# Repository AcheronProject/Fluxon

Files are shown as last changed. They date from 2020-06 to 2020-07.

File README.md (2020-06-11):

# Acheron 40-SM-S-STM32-MX-TH-WI (Codename "Fluxon")

Acheron Logo

See [this page](https://gondolindrim.github.io/AcheronDocs/fluxon/intro.html) for the Fluxon PCB documentation (still not written yet as of june of 2020).

## Introduction

The Fluxon is a replacement PCB for the Vortex Core keyboard. It supports the default layouts of the Vortex Core, with a 1.75-2.75 split spacebar. The PCB also supports two extra bottom row layouts: one with a 6.25 spacebar one and other with a 7 unit spacebar. See the picture below for details. 

The PCB is powered by a STM32L072CxTx and is QMK compatible.

The indicator LEDs of the stock PCB were substituted by SK6812 (WS2812-compatible controller-integrated seriallized RGB LEDs) which can be configured as per the QMK capabilities.

## Supported layouts

Click [this link](http://www.keyboard-layout-editor.com/#/gists/73be427d3e8086a9253feece2dae6974) for the KLE file for the Fluxon.

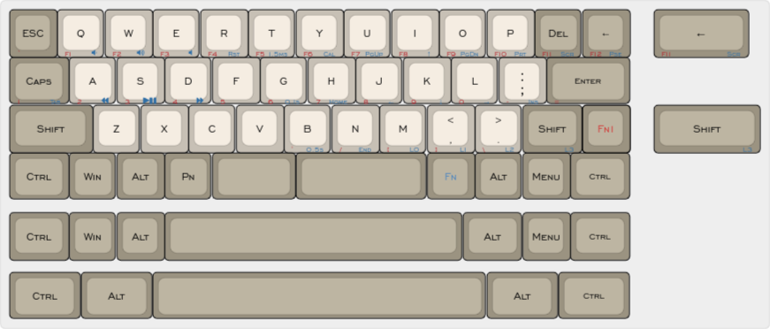
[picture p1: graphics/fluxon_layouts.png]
Fluxon layouts


## Renders

Fluxon bottom render
Fluxon top render

## Logo

The FLUXON logo was designed using the Deceptibots font by [Iconian Fonts](http://www.iconian.com/index.html). It was licensed for commercial use for this particular project through a donation. The FLUXON logo is therefore intellectual and commercial property of Álvaro "Gondolindrim" Volpato; the Deceptibots font is property of Iconian Fonts and their owners.

## Copyright notice

This project is released under the Acheron Open-Hardware License V1.2. For the license, please refer to the LICENCE.md file.

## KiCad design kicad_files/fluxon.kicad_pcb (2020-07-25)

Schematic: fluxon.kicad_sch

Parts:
C1, C2, C3: 100n; C_0805_2012Metric_Pad1.15x1.40mm_HandSolder
C4: 4.7nF; C_0805_2012Metric
C5, C6: 1u; CP_EIA-3216-10_Kemet-I_Pad1.58x1.35mm_HandSolder
C7: 4.7n; C_0805_2012Metric_Pad1.15x1.40mm_HandSolder
C8: 10u; C_0805_2012Metric_Pad1.15x1.40mm_HandSolder
C9, C10, C11, C15: 100n; C_0402_1005Metric
C12, C16: 4.7u; C_0402_1005Metric
C13: 1u; C_0402_1005Metric
C14: 10n; C_0402_1005Metric
C17: 1u; C_0805_2012Metric_Pad1.15x1.40mm_HandSolder
D1, D2, D3, D4, D5, D6, D7, D8, D9, D10, D11, D12, D13, D14, D15, D16, D17, D18, D19, D20, D21, D22, D23, D24, D25, D26, D27, D28, D29, D30, D31, D32, D33, D34, D35, D36, D37, D38, D39, D40, D41, D42, D43, D44, D45, D46, D47, D53: 1N4148W; D_SOD-123
D48, D49, D50: SK6812MINI-E; SK6812MINI_3535_6028_3.2x2.8mm_Round; MPN SK812MINI-E
D51: RB060M-60TR; D_SOD-123; Manufacturer Part Number RB060M-60TR; LCSC Part Number C114257
D52: SMF6.0A; D_SOD-123; Manufacturer Part Number SMF6.0A; LCSC Part Number C123790
F1: SL1210150; Fuse_1210_3225Metric; Manufacturer Part Number SL1210150; LCSC Part Number C70175
GR1: OSHLogo; osh-logo
GR2: Fluxon Plated Logo; fluxon_logo
GR3: Acheron Logo; acheronLong
GR4: Fluxon Big Logo; fluxon_logo_220x56.8mm
GR5, GR6, GR7: Warning Sign; warning_sign_3.6x3.2mm
J1: ARM SWD; Conn_ARM_JTAG_SWD_6
J2: U-F-M5DD-W-2; Korean-Hroparts_ U-F-M5DD-W-2; Manufacturer Part Number U-F-M5DD-W-2; LCSC Part Number C145793
J3: Conn_02x10; PinHeader_2x8_P2.54mm_Vertical
Q1: BSS138; SOT-23; Manufacturer Part Number BSS138; LCSC Part Number C193019
Q2: MUN5335DW1T1G; SOT-363_SC-70-6; Manufacturer Part Number MUN5335DW1T1G; LCSC Part Number C99680
R1, R2, R3: 3R; R_SMD_1206
R4, R6: 1k; R_SMD_1206
R5: 510R; R_SMD_1206
R7: 1M; R_SMD_1206
R8, R9, R13: 100k; R_SMD_1206
R10: 100R; R_SMD_1206
R11: 100; R_SMD_1206
R12: 33k; R_SMD_1206
S1: SW_Push; K2-1187SQ-A4SW-06; Manufacturer Part Number K2-1187SQ-A4SW-06; LCSC Part Number C92584
SW1: ESC; MX100
SW2: Q; MX100
SW3: W; MX100
SW4: E; MX100
SW5: R; MX100
SW6: T; MX100
SW7: Y; MX100
SW8: U; MX100
SW9: I; MX100
SW10: O; MX100
SW11: P; MX100
SW12: DEL; MX100
SW13: TAB_125; MX125
SW14: A; MX100
SW15: S; MX100
SW16: D; MX100
SW17: F; MX100
SW18: G; MX100
SW19: H; MX100
SW20: J; MX100
SW21: K; MX100
SW22: L; MX100
SW23: QUOTE; MX100
SW24: ENTER_175; MX175
SW25: LSHIFT_175; MX175
SW26: Z; MX100
SW27: X; MX100
SW28: C; MX100
SW29: V; MX100
SW30: B; MX100
SW31: N; MX100
SW32: M; MX100
SW33: COMMA; MX100
SW34: DOT; MX100
SW35: (D) RSHIFT_125; MX125
SW36: (D) FN_100; MX100
SW37: (F) RSHIFT_225; MX225
SW38: (I) RSHIFT_125; MX125
SW39: (I) SLASH_100; MX100
SW40: LCTRL_125; MX125
SW41: SUPER_100; MX100
SW42: LALT_100; MX100
SW43: SPC_625; MX625R
SW44: RALT_125; MX125
SW45: RGUI_100; MX100
SW46: RCTRL_125; MX125
SW47: BKSP; MX100
SW48: BKSP_2U; MX200
SW49: PN_100; MX100
SW50: SPC_175; MX175
SW51: SPC_275; MX275R
SW52: FN_100; MX100
SW53: RALT_100; MX100
SW54: LCTRL_150; MX150
SW55: LALT_150; MX150
SW56: SPC_700; MX700R
SW57: RCTRL_150; MX150
SW58: RALT_150; MX150
U1: USBLC6-2SC6; SOT-23-6; Manufacturer Part Number USBLC6-2SC6; LCSC Part Number C7519
U2: MCP1700-3302E/TT; SOT-23; Manufacturer Part Number MCP1700-3302E/TT; LCSC Part Number C39051
U3: STM32L072CBT6; LQFP-48_7x7mm_P0.5mm; Manufacturer Part Number STM32F072CBT6; LCSC Part Number C465977

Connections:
3.3V: C6.1, C9.2, C10.1, C11.2, C12.2, C13.2, C14.2, C15.2, C16.2, D51.2 (A), J1.1, J3.15, Q2.4 (C), R9.2, S1.1, U2.2 (VO), U3.1 (VBAT), U3.9 (VDDA), U3.24 (VDD), U3.36 (VDDIO2), U3.48 (VDD)
5V: C5.1, D51.1 (K), D52.1 (K), F1.1, R1.2, R2.1, R3.2, R4.2, R5.2, R8.2, U2.3 (VI)
/SHIELD: C4.2, J2.6 (Shield), R7.1
BOOT0: C8.2, R11.2, R12.1, R13.2, U3.44 (BOOT0)
Col1: SW1.1 (Col), SW13.1 (Col), SW25.1 (Col), SW40.1 (Col), SW54.1 (Col), U3.25 (PB12)
Col2: SW2.2 (Row), SW14.2 (Row), SW26.1 (Col), SW41.1 (Col), U3.11 (PA1/ADC_IN1)
Col3: SW3.1 (Col), SW15.1 (Col), SW27.1 (Col), SW42.1 (Col), SW55.1 (Col), U3.10 (PA0/ADC_IN0)
Col4: SW4.1 (Col), SW16.1 (Col), SW28.1 (Col), SW49.1 (Col), U3.6 (PF1/OSC_OUT)
Col5: SW5.1 (Col), SW17.1 (Col), SW29.1 (Col), SW50.1 (Col), U3.5 (PF0/OSC_IN)
Col6: SW6.1 (Col), SW18.1 (Col), SW30.1 (Col), SW43.1 (Col), SW51.1 (Col), SW56.1 (Col), U3.4 (PC15/OSC32_OUT)
Col7: SW7.1 (Col), SW19.1 (Col), SW31.1 (Col), U3.3 (PC14/OSC32_IN)
Col8: SW8.1 (Col), SW20.1 (Col), SW32.1 (Col), SW52.1 (Col), U3.2 (PC13)
Col9: SW9.1 (Col), SW21.1 (Col), SW33.1 (Col), SW44.1 (Col), SW53.1 (Col), SW57.1 (Col), U3.46 (SPI2_NSS/I2S2_WS/I2C1_SDA/TIM17_CH1/PB9)
Col10: SW10.1 (Col), SW22.1 (Col), SW34.1 (Col), SW45.1 (Col), U3.45 (I2C1_SCL/TIM16_CH1/PB8)
Col11: SW11.1 (Col), SW23.1 (Col), SW35.1 (Col), SW37.1 (Col), SW39.1 (Col), SW46.1 (Col), SW58.1 (Col), U3.43 (2C1_SDA/PB7)
Col12: SW12.1 (Col), SW24.1 (Col), SW36.1 (Col), SW38.1 (Col), SW47.2 (Row), SW48.2 (Row), U3.41 (SPI1_MOSI/I2S1_SD/TIM3_CH2/PB5)
D+: U1.6 (I/O1), U3.33 (USB_DP/PA12)
D-: U1.4 (I/O2), U3.32 (USB_DM/TIM1_CH4/PA11)
DBus+: J2.3 (D+), U1.1 (I/O1)
DBus-: J2.2 (D-), U1.3 (I/O2)
EXTRA3: J3.1, U3.30 (TIM1_CH2/PA9)
EXTRA5: J3.3, U3.29 (TIM1_CH1/PA8)
EXTRA6: J3.2, U3.31 (TIM1_CH3/PA10)
EXTRA8: J3.4, U3.27 (SPI2_MISO/I2S2_MCK/I2C2_SDA/TIM15_CH1/P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)
EXTRA9: J3.5, U3.22 (PB11/TIM2_CH4/I2C2_SDA)
EXTRA10: J3.6, U3.21 (PB10/SPI2_SCK/I2C2_SCL/TIM2_CH3)
EXTRA11: J3.7, U3.20 (PB2)
EXTRA12: J3.8, U3.19 (PB1/TIM3_CH4/TIM14_CH1/ADC_IN9)
EXTRA13: J3.9, U3.18 (PB0/TIM3_CH3/ADC_IN8)
EXTRA14: J3.10, U3.17 (PA7/TIM3_CH2/TIM14_CH1/ADC_IN7)
EXTRA15: J3.11, U3.16 (PA6/ADC_IN6/TIM3_CH1/TIM16_CH1)
EXTRA16: J3.12, U3.15 (PA5/ADC_IN5/DAC_OUT2)
EXTRA17: J3.13, U3.14 (PA4/TIM14_CH1/ADC_IN4)
EXTRA18: J3.14, U3.13 (PA3/TIM15_CH2/ADC_IN3)
GND: C1.1, C2.1, C3.1, C4.1, C5.2, C6.2, C7.2, C8.1, C9.1, C10.2, C11.1, C12.1, C13.1, C14.1, C15.1, C16.1, C17.1, D48.3 (VSS), D49.3 (VSS), D50.3 (VSS), D52.2 (A), J1.5, J2.5 (GND), J3.16, Q2.1 (C), R6.1, R7.2, R8.1, R9.1, R13.1, U1.2 (GND), U2.1 (GND), U3.8 (VSSA), U3.23 (VSS), U3.35 (VSS), U3.47 (VSS)
NRST: C7.1, J1.3, R10.2, U3.7 (NRST)
unnamed: C1.2, D48.1 (VDD), R1.1
unnamed: C2.2, D49.1 (VDD), R2.2
unnamed: C3.2, D50.1 (VDD), R3.1
unnamed: C17.2, Q1.1 (G), R5.1, R6.2
unnamed: D1.2 (A), SW1.2 (Row)
unnamed: D2.2 (A), SW2.1 (Col)
unnamed: D3.2 (A), SW3.2 (Row)
unnamed: D4.2 (A), SW4.2 (Row)
unnamed: D5.2 (A), SW5.2 (Row)
unnamed: D6.2 (A), SW6.2 (Row)
unnamed: D7.2 (A), SW7.2 (Row)
unnamed: D8.2 (A), SW8.2 (Row)
unnamed: D9.2 (A), SW9.2 (Row)
unnamed: D10.2 (A), SW10.2 (Row)
unnamed: D11.2 (A), SW11.2 (Row)
unnamed: D12.2 (A), SW12.2 (Row)
unnamed: D13.2 (A), SW13.2 (Row)
unnamed: D14.2 (A), SW14.1 (Col)
unnamed: D15.2 (A), SW15.2 (Row)
unnamed: D16.2 (A), SW16.2 (Row)
unnamed: D17.2 (A), SW17.2 (Row)
unnamed: D18.2 (A), SW18.2 (Row)
unnamed: D19.2 (A), SW19.2 (Row)
unnamed: D20.2 (A), SW20.2 (Row)
unnamed: D21.2 (A), SW21.2 (Row)
unnamed: D22.2 (A), SW22.2 (Row)
unnamed: D23.2 (A), SW23.2 (Row)
unnamed: D24.2 (A), SW24.2 (Row)
unnamed: D25.2 (A), SW25.2 (Row)
unnamed: D26.2 (A), SW26.2 (Row)
unnamed: D27.2 (A), SW27.2 (Row)
unnamed: D28.2 (A), SW28.2 (Row)
unnamed: D29.2 (A), SW29.2 (Row)
unnamed: D30.2 (A), SW30.2 (Row)
unnamed: D31.2 (A), SW31.2 (Row)
unnamed: D32.2 (A), SW32.2 (Row)
unnamed: D33.2 (A), SW33.2 (Row)
unnamed: D34.2 (A), SW34.2 (Row)
unnamed: D35.2 (A), SW35.2 (Row), SW37.2 (Row), SW39.2 (Row)
unnamed: D36.2 (A), SW36.2 (Row), SW38.2 (Row)
unnamed: D37.2 (A), SW40.2 (Row), SW54.2 (Row)
unnamed: D38.2 (A), SW41.2 (Row)
unnamed: D39.2 (A), SW42.2 (Row), SW55.2 (Row)
unnamed: D40.2 (A), SW43.2 (Row), SW51.2 (Row), SW56.2 (Row)
unnamed: D41.2 (A), SW44.2 (Row), SW53.2 (Row), SW57.2 (Row)
unnamed: D42.2 (A), SW45.2 (Row)
unnamed: D43.2 (A), SW46.2 (Row), SW58.2 (Row)
unnamed: D44.2 (A), SW47.1 (Col), SW48.1 (Col)
unnamed: D45.2 (A), SW49.2 (Row)
unnamed: D46.2 (A), SW50.2 (Row)
unnamed: D47.2 (A), SW52.2 (Row)
unnamed: D48.2 (DOUT), D49.4 (DIN)
unnamed: D49.2 (DOUT), D50.4 (DIN)
unnamed: D53.1 (K), R12.2
unnamed: D53.2 (A), Q2.2 (B), S1.2
unnamed: Q2.3 (C), R11.1
unnamed: Q2.6 (C), R10.1
RGB_3V3: Q1.2 (S), U3.28 (SPI2_MOSI/I2S2_SD/PB15)
RGB_5V: D48.4 (DIN), Q1.3 (D), R4.1
Row1: D1.1 (K), D2.1 (K), D3.1 (K), D4.1 (K), D5.1 (K), D6.1 (K), D7.1 (K), D8.1 (K), D9.1 (K), D10.1 (K), D11.1 (K), D12.1 (K), U3.38 (PA15)
Row2: D13.1 (K), D14.1 (K), D15.1 (K), D16.1 (K), D17.1 (K), D18.1 (K), D19.1 (K), D20.1 (K), D21.1 (K), D22.1 (K), D23.1 (K), D24.1 (K), U3.39 (SPI1_SCK/I2S1_CK/TIM2_CH2/PB3)
Row3: D25.1 (K), D26.1 (K), D27.1 (K), D28.1 (K), D29.1 (K), D30.1 (K), D31.1 (K), D32.1 (K), D33.1 (K), D34.1 (K), D35.1 (K), D36.1 (K), U3.12 (PA2/ADC_IN2)
Row4: D37.1 (K), D38.1 (K), D39.1 (K), D40.1 (K), D41.1 (K), D42.1 (K), D43.1 (K), D44.1 (K), D45.1 (K), D46.1 (K), D47.1 (K), U3.42 (I2C1_SCL/PB6)
SOFT_RESET: Q2.5 (B), U3.40 (SPI1_MISO/I2S1_MCK/TIM3_CH1/PB4)
SWCLK: J1.4, U3.37 (SWCLK/PA14)
SWDIO: J1.2, U3.34 (SWDIO/PA13)
VBUS: F1.2, J2.1 (VBUS), U1.5 (VBUS)

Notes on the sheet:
Shield
USB Connector
USD ESD
(D) Default bottom row
(T) Tsangan bottom row
(L) "Long" 6.25 bottom row
Serial programming
Power supply and protection circuit
Logos and flags
RGB indicators
Hard reset circuit
MCU
CBx are the bypass capacitors. Their value is specified in reference [2].

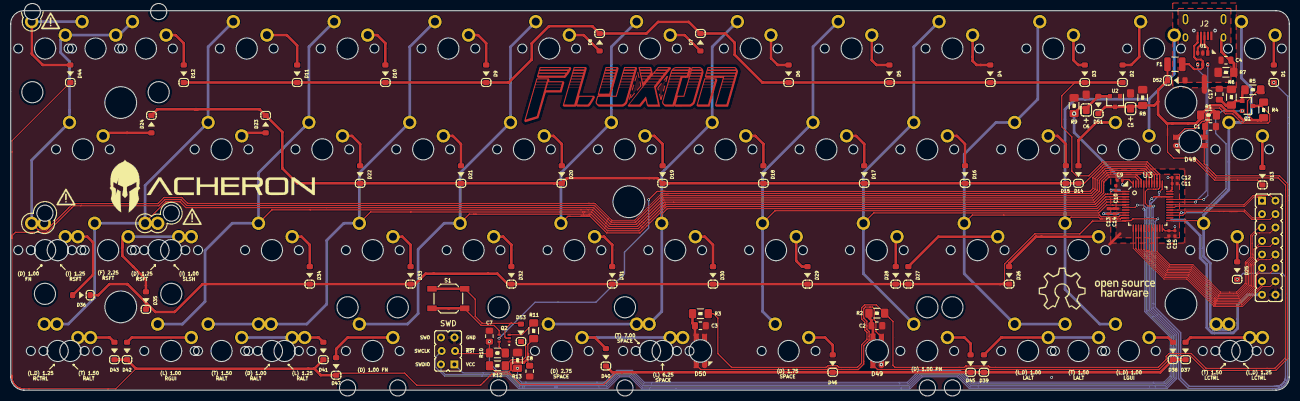
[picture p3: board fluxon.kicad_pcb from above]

Board: 2 copper layers, 241.6 x 71.7 mm, 158 parts (1 on the bottom side), 103 nets.

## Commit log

2020-06-10 Add README and LICENSE
    [fluxon.kicad_pcb, fluxon.kicad_sch]
2020-06-11 Add software reset circuit
    [fluxon.kicad_pcb, fluxon.kicad_sch]
2020-06-11 Finish routing
    [fluxon.kicad_pcb, fluxon.kicad_sch]
2020-07-24 Quality of circuit improvements
    - Adoption of STM32L072 MCU variant
    - Changed TVS to SMF6.0A unidirectional
    - Addition of regulation capacitor to voltage divider resistors in the level shifter circuit
    [fluxon.kicad_pcb, fluxon.kicad_sch]
2020-07-24 Change LDO bypass capacitors to tantallum
    [fluxon.kicad_pcb, fluxon.kicad_sch]
2020-07-25 Change ARM SWD JTAG to 6 pin variant
    [fluxon.kicad_pcb, fluxon.kicad_sch]
2020-07-25 Silkscreen and tracing improvements
    [fluxon.kicad_pcb, fluxon.kicad_sch]
